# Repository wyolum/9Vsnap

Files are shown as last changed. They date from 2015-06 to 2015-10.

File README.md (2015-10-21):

# 9Vsnap
snaps in to 9V battery and provides 3V3 or 5V0 output

forked from snapVCC [https://hackaday.io/project/6269-snapvcc] by [Mahesh Venkitachalam] https://hackaday.io/electronut. This version attempts to make the size of the PCB match the cross-section of the battery. I also want to use is as a demo project while doing KiCad 101

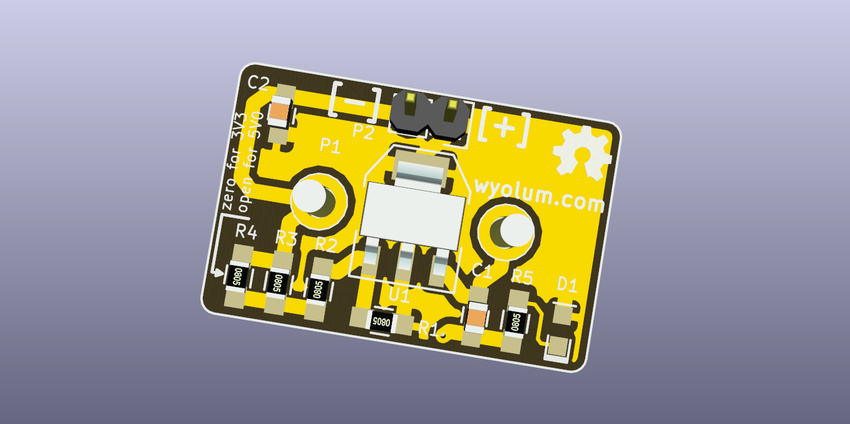
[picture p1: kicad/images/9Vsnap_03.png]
Top view of 9Vsnap


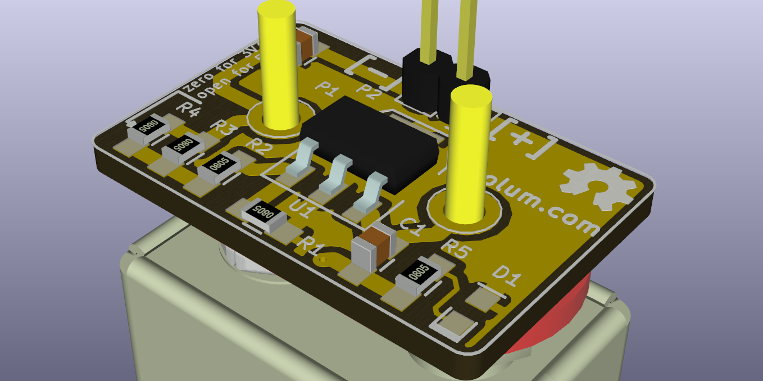
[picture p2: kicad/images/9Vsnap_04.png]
9Vsnap attached to a battery


License
-------
[CERN Open Hardware Licence v1.2 ]

[CERN Open Hardware Licence v1.2 ]:http://www.ohwr.org/attachments/2388/cern_ohl_v_1_2.txt

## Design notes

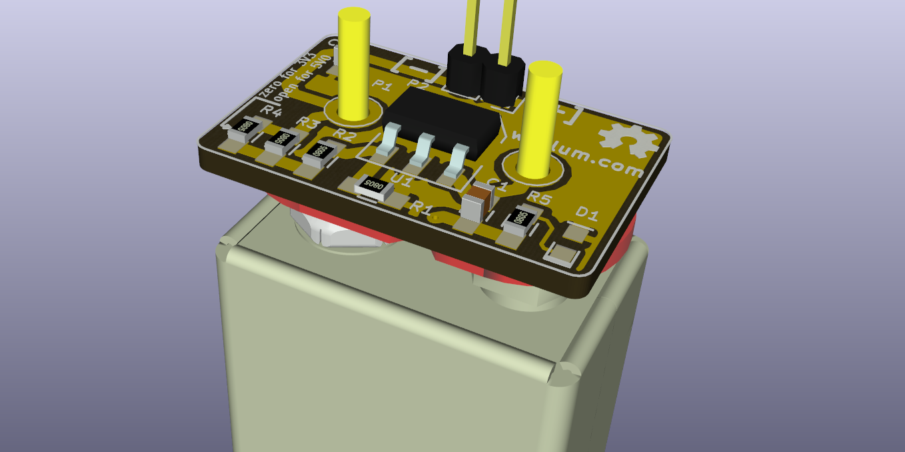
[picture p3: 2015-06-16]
kicad/images/9Vsnap_02.png

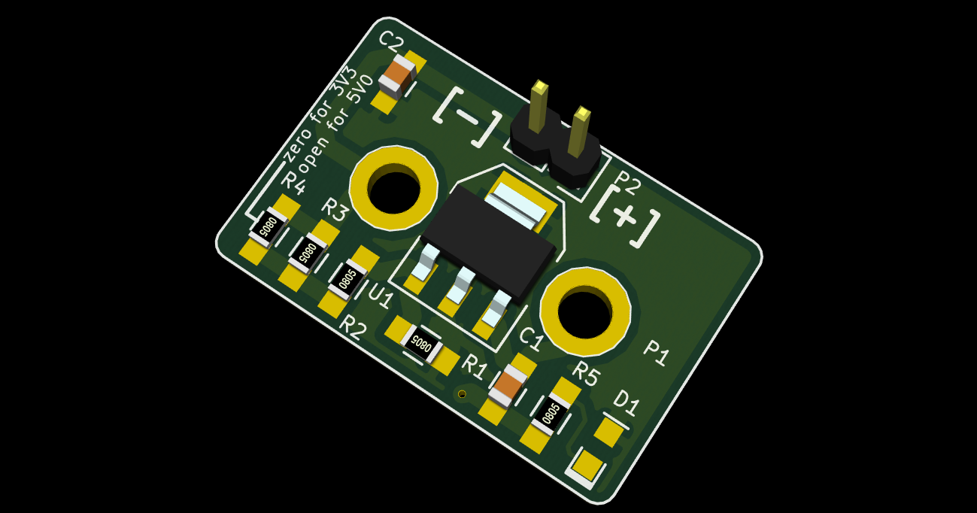
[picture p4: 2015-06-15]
kicad/images/9Vsnap_01.png

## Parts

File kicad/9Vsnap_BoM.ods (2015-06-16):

Id | Designator | Package | Quantity | Designation | Mfr. P/N | Digikey P/N | Price | Link
1 | C1 | C_0805_HandSoldering | 1 | 100n | CL21B104KBCNNNC | 1276-1003-1-ND | 0.10 | http://www.digikey.com/product-detail/en/CL21B104KBCNNNC/1276-1003-1-ND/3889089
2 | C2 | C_0805_HandSoldering | 1 | 1uF | CL21F105ZOCNNNC | 1276-1246-1-ND | 0.10 | http://www.digikey.com/product-detail/en/CL21F105ZOCNNNC/1276-1246-1-ND/3889332
3 | D1 | LED-0805 | 1 | LED | LTST-C170EKT | 160-1178-1-ND | 0.36 | http://www.digikey.com/product-detail/en/LTST-C170EKT/160-1178-1-ND/269250
4 | P1 | 9V_clip_968 | 1 | 9V_IN | 968 | 36-968-ND | 1.21 | http://www.digikey.com/product-search/en?x=0&y=0&lang=en&site=us&keywords=36-968-ND
5 | P2 | Pin_Header_Straight_1x02 | 1 | OUT
6 | R1 | R_0805_HandSoldering | 1 | 240 | CRCW0805240RJNEA | 541-240ACT-ND | 0.08 | http://www.digikey.com/product-detail/en/CRCW0805240RJNEA/541-240ACT-ND/1180325
7 | R2 | R_0805_HandSoldering | 1 | 390 | CRCW0805390RJNEA | 541-390ACT-ND | 0.08 | http://www.digikey.com/product-detail/en/CRCW0805390RJNEA/541-390ACT-ND/1180330
8 | R4 | R_0805_HandSoldering | 1 | R0
9 | R5,R3 | R_0805_HandSoldering | 2 | 330 | CRCW0805330RJNEA | 541-330ACT-ND | 0.08 | http://www.digikey.com/product-detail/en/CRCW0805330RJNEA/541-330ACT-ND/1180328
10 | U1 | SOT-223 | 1 | LM317EMP | LM317DCYR | 296-12602-1-ND | 0.80 | http://www.digikey.com/product-detail/en/LM317DCYR/296-12602-1-ND/443738
 |  |  |  |  |  |  | 2.801

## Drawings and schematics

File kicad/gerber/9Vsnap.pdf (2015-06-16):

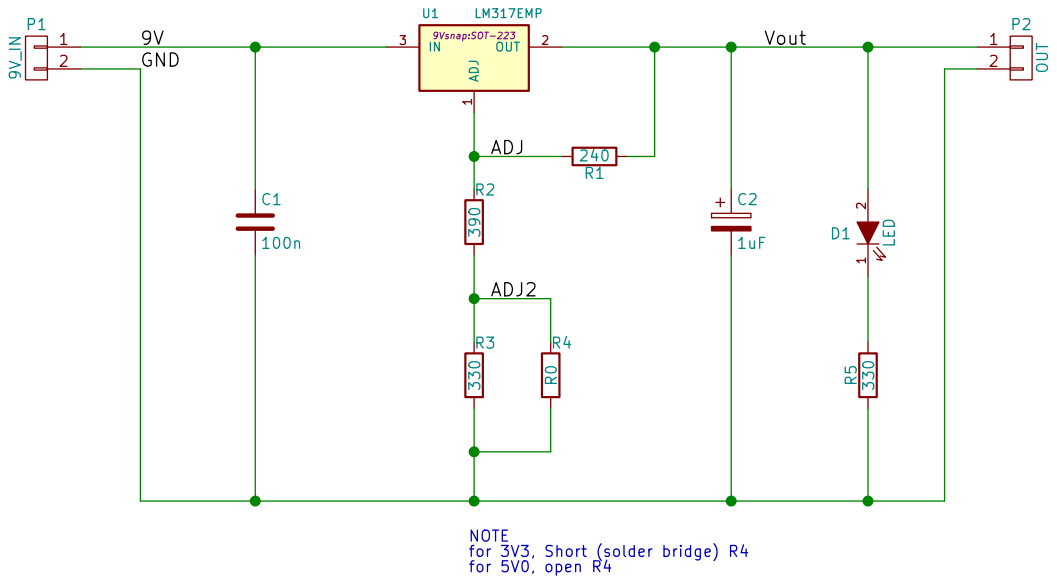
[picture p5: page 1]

NOTE
for 3V3, Short (solder bridge) R4
for 5V0, open R4

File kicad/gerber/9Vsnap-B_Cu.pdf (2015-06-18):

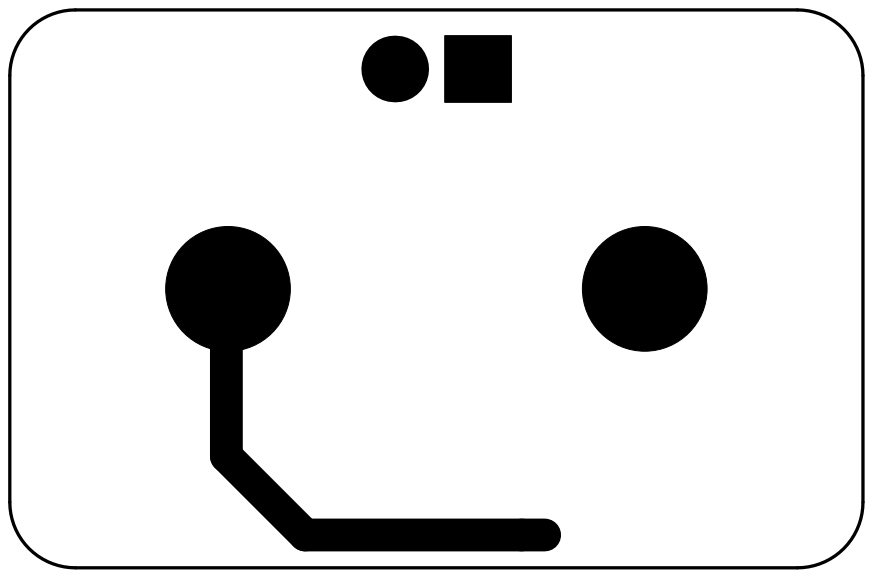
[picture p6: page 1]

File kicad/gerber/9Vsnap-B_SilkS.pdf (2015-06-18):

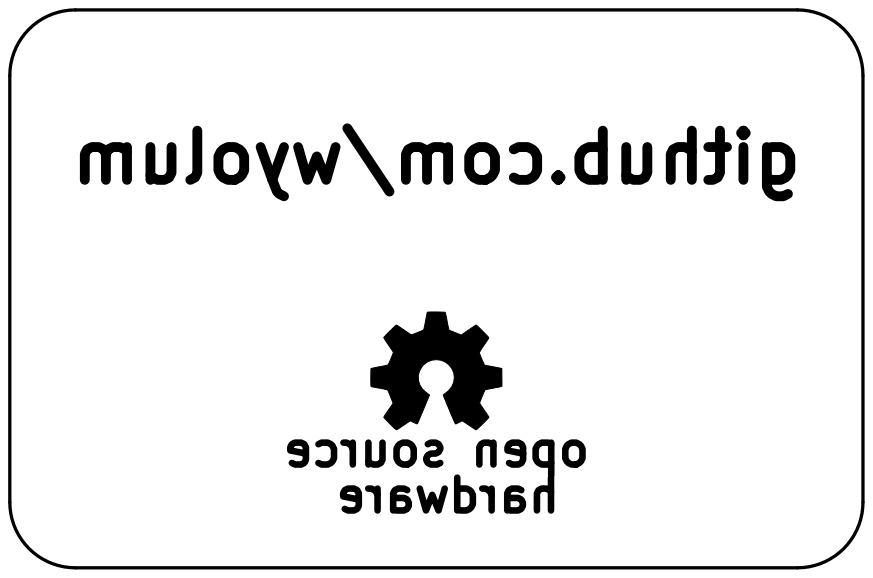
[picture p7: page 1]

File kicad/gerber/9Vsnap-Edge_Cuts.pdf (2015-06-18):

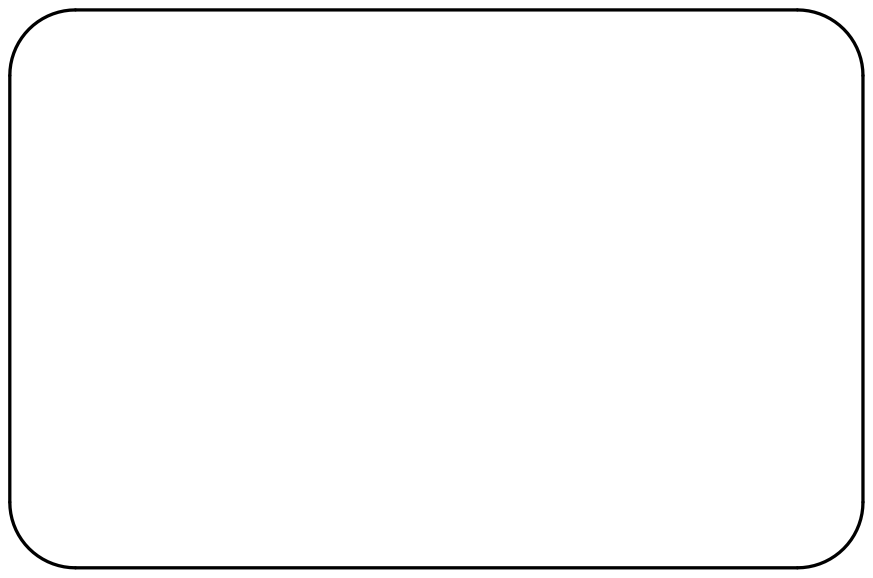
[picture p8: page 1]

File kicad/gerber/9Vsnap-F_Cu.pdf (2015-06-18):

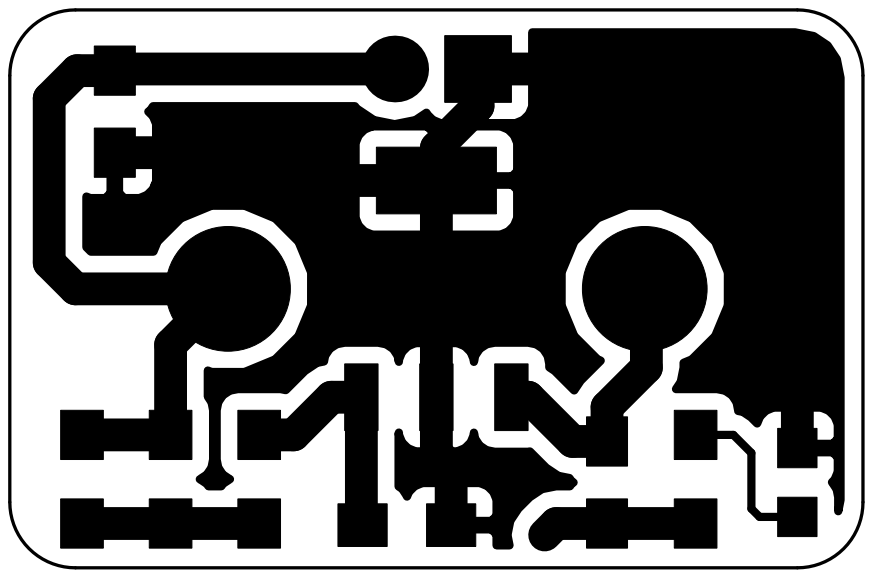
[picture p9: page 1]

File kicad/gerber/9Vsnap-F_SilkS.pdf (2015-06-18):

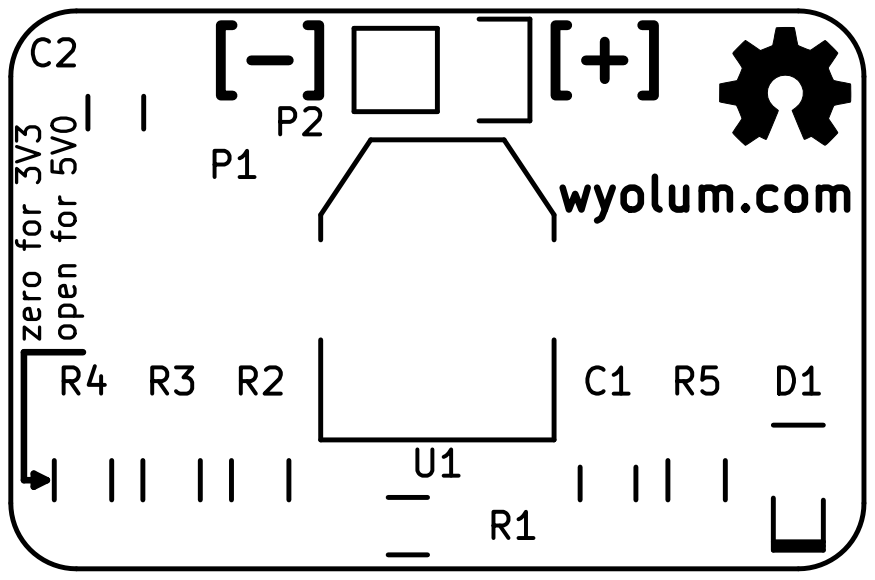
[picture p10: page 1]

wyolum.com zero for 3V3 open for 5V0

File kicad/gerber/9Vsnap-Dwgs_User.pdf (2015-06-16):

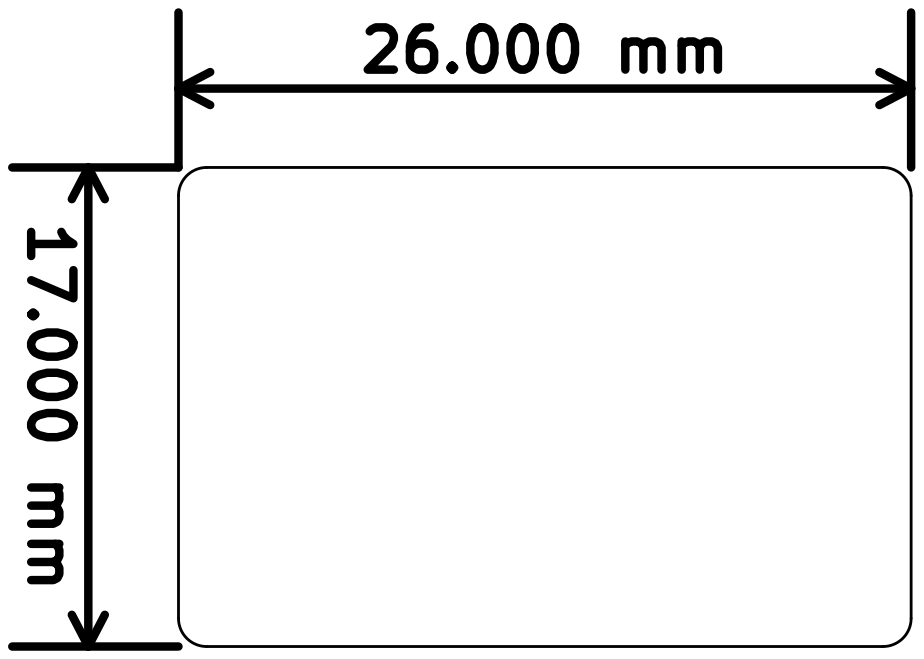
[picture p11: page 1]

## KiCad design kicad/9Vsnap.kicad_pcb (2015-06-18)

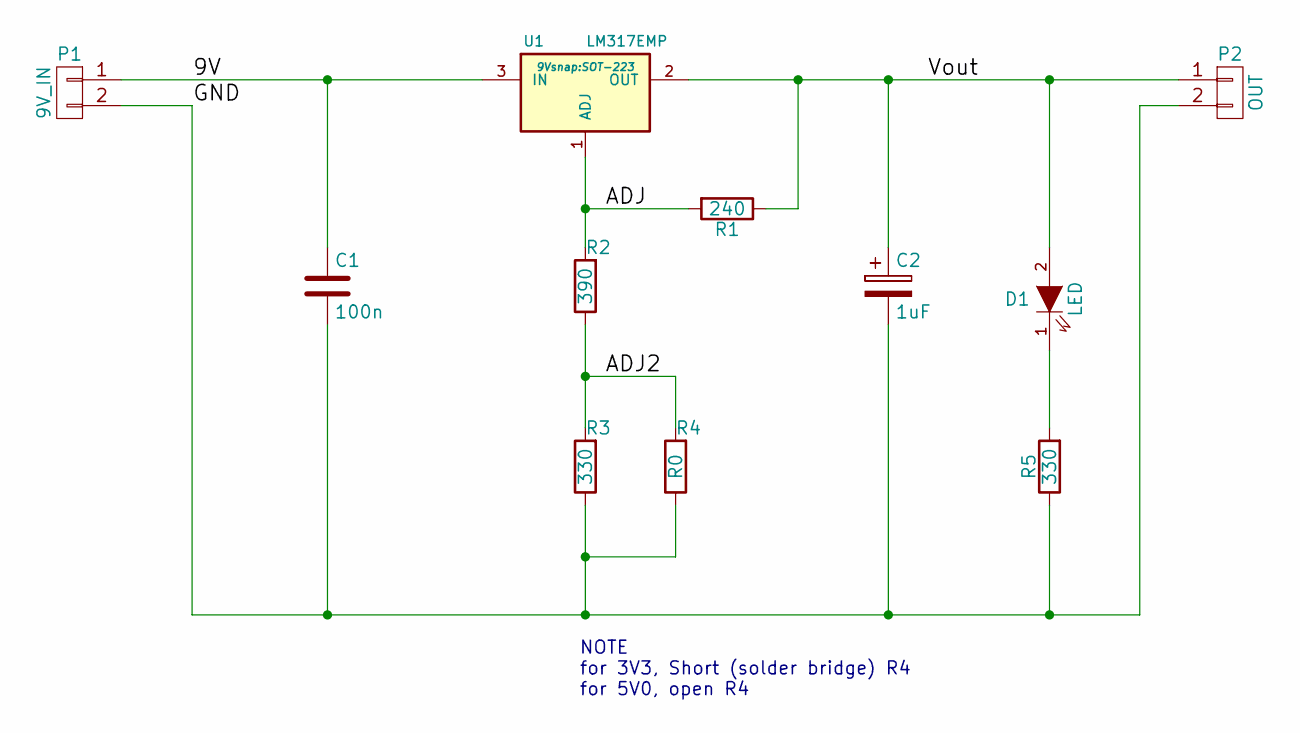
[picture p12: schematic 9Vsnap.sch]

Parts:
C1: 100n; C_0805_HandSoldering
C2: 1uF; C_0805_HandSoldering
D1: LED; LED-0805
P1: 9V_IN; 9V_clip_968
P2: OUT; Pin_Header_Straight_1x02
R1: 240; R_0805_HandSoldering
R2: 390; R_0805_HandSoldering
R3, R5: 330; R_0805_HandSoldering
R4: R0; R_0805_HandSoldering
U1: LM317EMP; SOT-223

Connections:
/9V: C1.1, P1.1, U1.3 (IN)
/ADJ: R1.2, R2.2, U1.1 (ADJ)
/ADJ2: R2.1, R3.2, R4.2
/GND: C1.2, C2.2, P1.2, P2.2, R3.1, R4.1, R5.1
/Vout: C2.1, D1.2 (A), P2.1, R1.1, U1.2 (OUT)
unnamed: D1.1 (K), R5.2

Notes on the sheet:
NOTE for 3V3, Short (solder bridge) R4 for 5V0, open R4

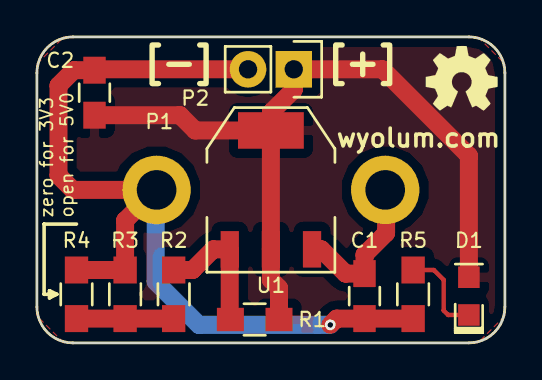
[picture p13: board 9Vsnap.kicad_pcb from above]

Board: 2 copper layers, 26.0 x 17.0 mm, 11 parts (0 on the bottom side), 6 nets.

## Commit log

2015-06-15 looks done but need to verify
    [9Vsnap.kicad_pcb, 9Vsnap.sch, 9Vsnap_BoM_sch.csv]
2015-06-16 Done. Gerbers ready
    [9Vsnap-B_Cu.gbl, 9Vsnap-B_Mask.gbs, 9Vsnap-B_SilkS.gbo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]
2015-06-18 increased radius of board corners
    [9Vsnap.kicad_pcb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]
